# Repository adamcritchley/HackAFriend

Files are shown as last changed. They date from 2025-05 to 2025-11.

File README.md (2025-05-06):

# Hack-A-Friend Handheld Gaming Console

### Hone your hacking skills with the **Hack-A-Friend** gaming handheld!  
Delve into epic **CTF attack and defend** style games with your friends. Challenge opponents by **attacking their devices** while defending your own. The winner unleashes a **devastating payload** to dominate their opponent’s game.

---

## 🔥 Features

- **CTF-style gameplay** – Attack and defend devices in real-time battles.
- **Custom payloads** – Winners can craft unique in-game exploits.
- **Open-source** – Clone our upcoming [GitHub repository](#) and create your own games and payloads.
- **Interactive LEDs** – Visual cues for game status and exploit notifications.
- **Bootloader customization** – Recover or modify firmware when needed.

---

## 🔧 Hardware Specifications

- **Power System**:
  - Lithium-ion battery management chip.
  - 500mA LDO for regulated power.
  - Test points for monitoring:
    - `VCC` (battery power source).
    - `3V3` (regulated output from LDO).

- **LED Indicators**:
  - **System notifications**:
    - `PWR` (Power Health LED).
    - `CHG` (Battery Charging LED).
  - **Game Status**:
    - **NeoPixel**:
      - Off – Game idle.
      - Green – Game active.
      - Red – Device under exploitation.
    - **User-Controlled LEDs**:
      - Two standard LEDs for custom exploit visualizations.

- **Debugging & Recovery**:
  - **Test points** for SDA & SCL (I2C debugging with digital signal analyzer).
  - **Bootloader Recovery**:
    - Uses **10-pin ARM TagConnect footprint** (`TC2050-IDC-NL` cable).
    - Compatible with **SWD** and **JTAG** devices like `nRF52840 DK`.
    - Recovery via `nrf-utils` and official bootloader image.
    - **Segger J-Link compatibility

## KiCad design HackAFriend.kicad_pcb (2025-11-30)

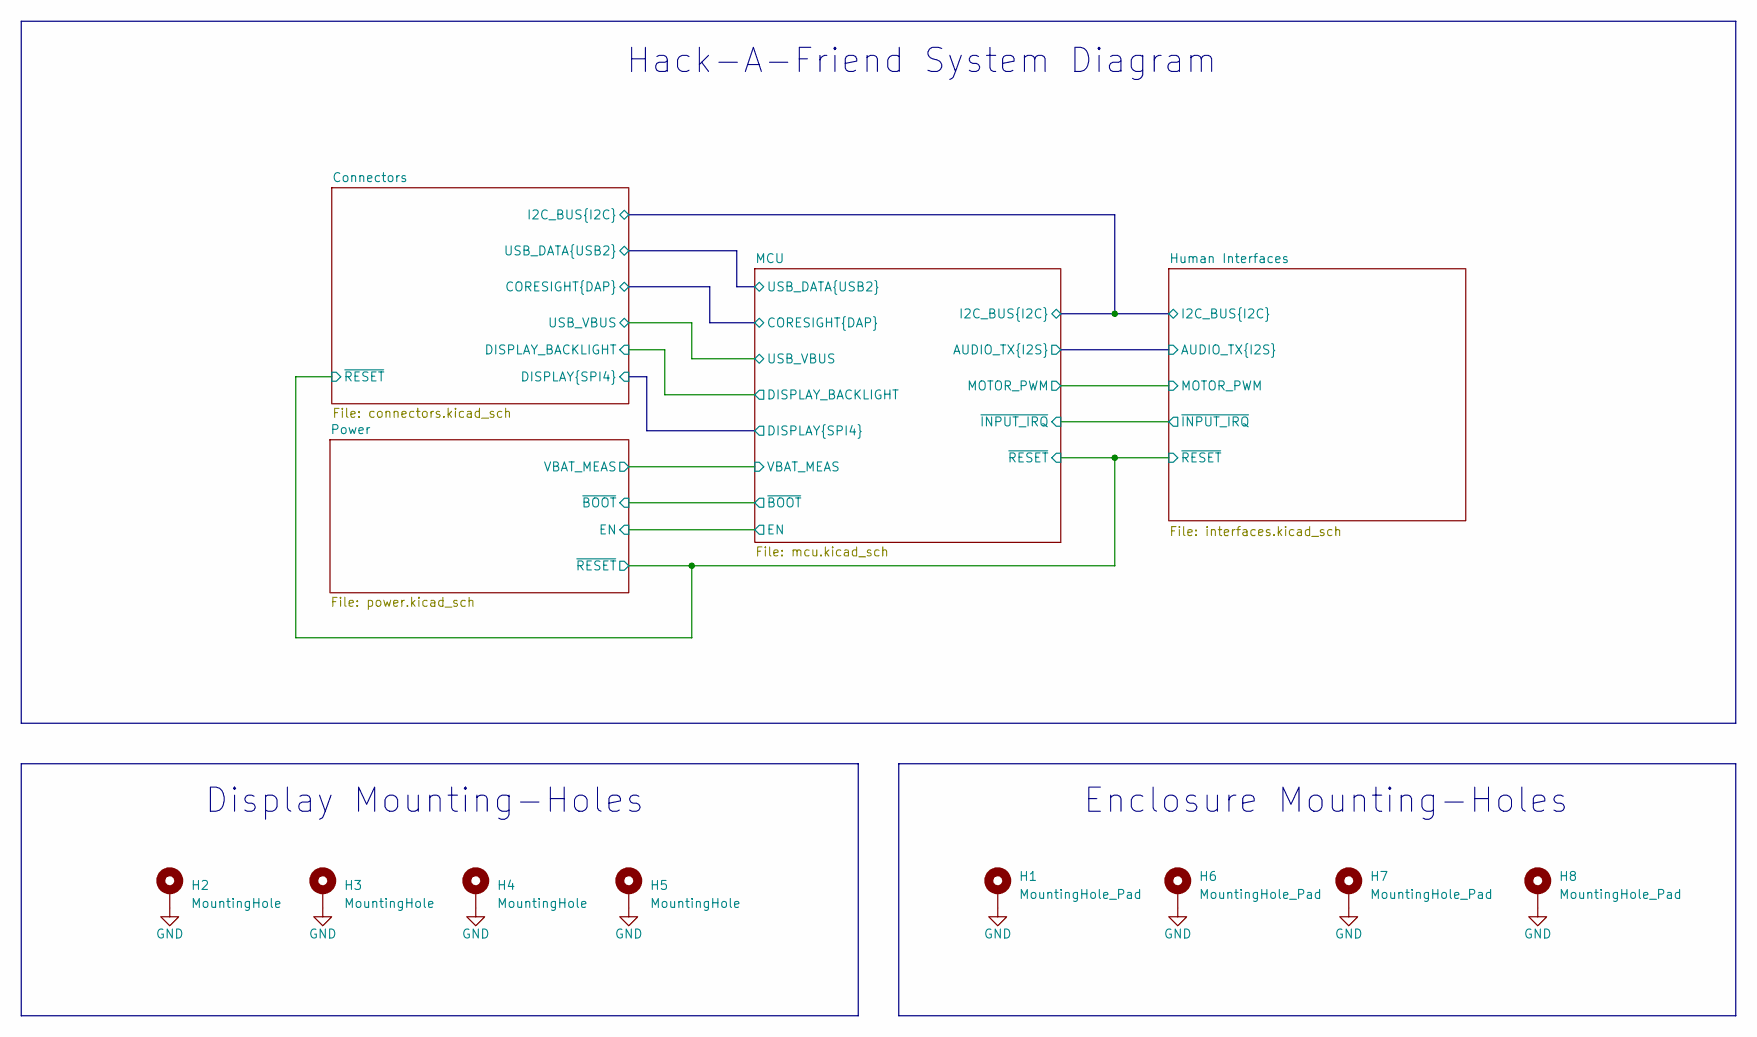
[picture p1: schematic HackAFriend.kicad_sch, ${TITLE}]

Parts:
H1, H6, H7, H8: MountingHole_Pad; MountingHole_2.7mm_M2.5_DIN965_Pad
H2, H3, H4, H5: MountingHole; MountingHole_2.5mm_Pad

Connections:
GND: H1.1, H2.1, H3.1, H4.1, H5.1, H6.1, H7.1, H8.1; also elsewhere on the board

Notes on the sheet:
Display Mounting-Holes
Hack-A-Friend System Diagram
Enclosure Mounting-Holes

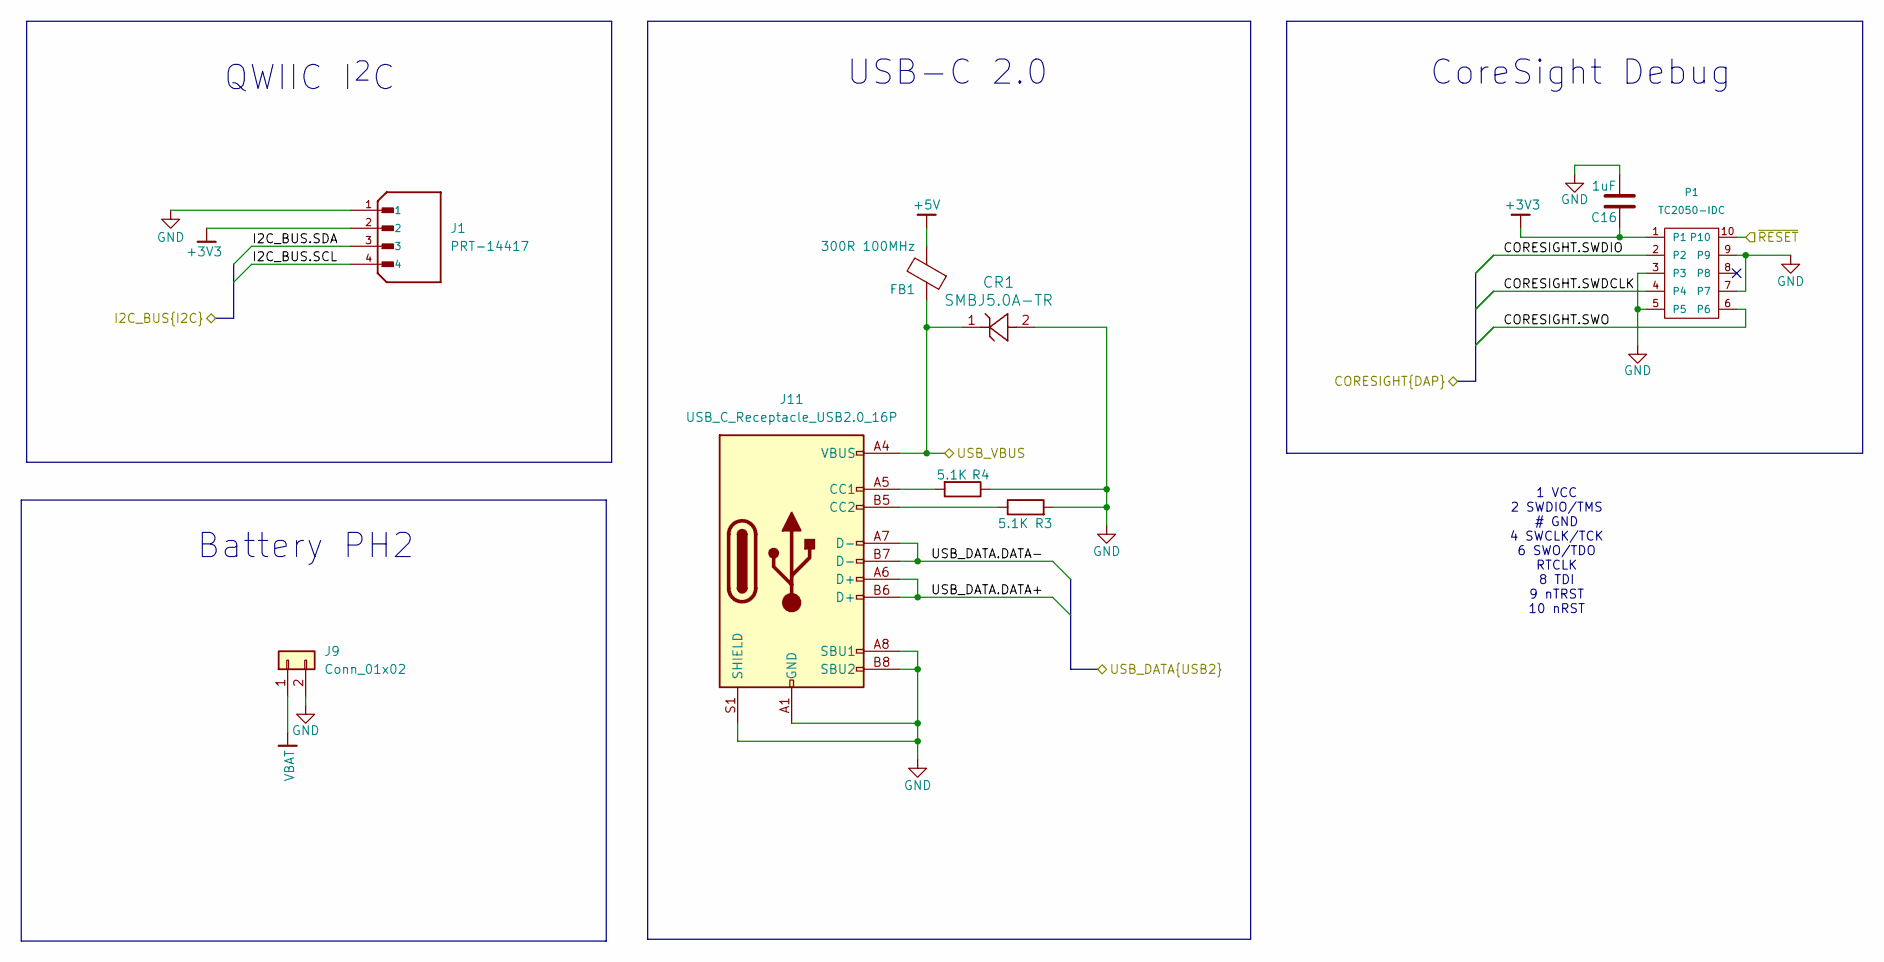
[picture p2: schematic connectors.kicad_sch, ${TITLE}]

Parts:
C16: 1uF; C_0402_1005Metric
CR1: SMBJ5.0A-TR; SMB_STM
FB1: 300R 100MHz; L_0805_2012Metric
J1: PRT-14417; SPARKFUN_PRT-14417; PARTREV NA
J9: Conn_01x02; JST_PH_S2B-PH-K_1x02_P2.00mm_Horizontal
J11: USB_C_Receptacle_USB2.0_16P; USB_C_Receptacle_GCT_USB4105-xx-A_16P_TopMnt_Horizontal
P1: TC2050-IDC; Tag-Connect_TC2050-IDC-FP_2x05_P1.27mm_Vertical
R3, R4: 5.1K; R_0402_1005Metric

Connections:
+3V3: C16.1, J1.2, P1.1; also elsewhere on the board
+5V: FB1.2; also elsewhere on the board
/Connectors/CORESIGHT.SWDCLK: P1.4; also elsewhere on the board
/Connectors/CORESIGHT.SWDIO: P1.2; also elsewhere on the board
/Connectors/CORESIGHT.SWO: P1.6; also elsewhere on the board
/Connectors/I2C_BUS.SCL: J1.4; also elsewhere on the board
/Connectors/I2C_BUS.SDA: J1.3; also elsewhere on the board
/Connectors/USB_DATA.DATA+: J11.A6 (D+), J11.B6 (D+); also elsewhere on the board
/Connectors/USB_DATA.DATA-: J11.A7 (D-), J11.B7 (D-); also elsewhere on the board
/Connectors/USB_VBUS: CR1.1, FB1.1, J11.A4 (VBUS), J11.A9 (VBUS), J11.B4 (VBUS), J11.B9 (VBUS); also elsewhere on the board
/Connectors/~RESET: P1.10; also elsewhere on the board
GND: C16.2, CR1.2, J1.1, J9.2, J11.A1 (GND), J11.A8 (SBU1), J11.A12 (GND), J11.B1 (GND), J11.B8 (SBU2), J11.B12 (GND), J11.S1 (SHIELD), P1.3, P1.5, P1.7, P1.9, R3.2, R4.1; also elsewhere on the board
unnamed: J11.A5 (CC1), R4.2
unnamed: J11.B5 (CC2), R3.1
VBAT: J9.1; also elsewhere on the board

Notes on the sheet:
USB-C 2.0
Battery PH2
QWIIC I^{2}C
1 VCC 2 SWDIO/TMS # GND 4 SWCLK/TCK 6 SWO/TDO RTCLK 8 TDI 9 nTRST 10 nRST
CoreSight Debug

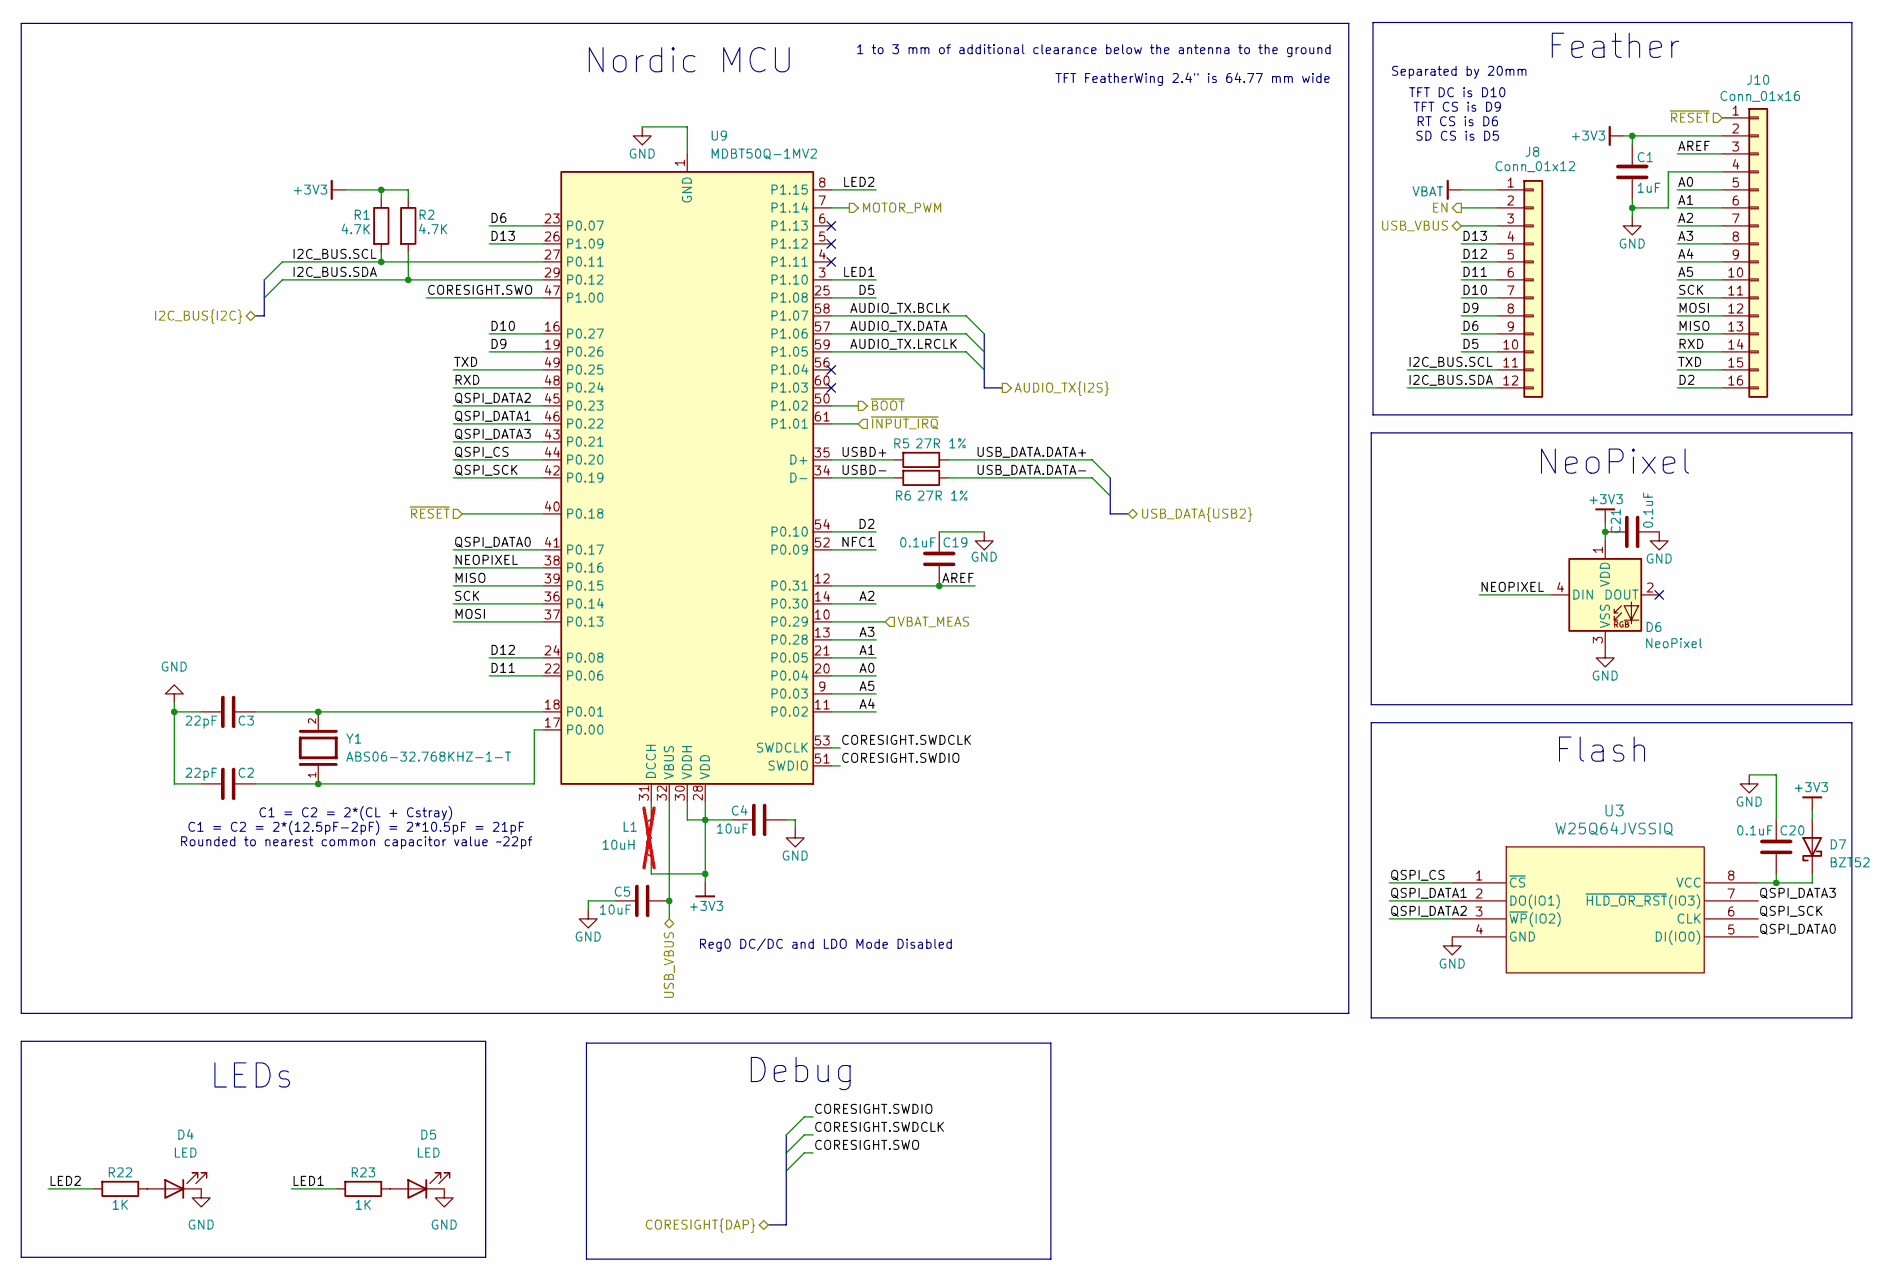
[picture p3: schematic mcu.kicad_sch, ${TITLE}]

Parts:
C1: 1uF; C_0402_1005Metric
C2, C3: 22pF; C_0603_1608Metric
C4, C5: 10uF; C_0603_1608Metric
C19, C20, C21: 0.1uF; C_0402_1005Metric
D4, D5: LED; LED_0603_1608Metric
D6: NeoPixel; LED_WS2812B_PLCC4_5.0x5.0mm_P3.2mm
D7: BZT52; D_0402_1005Metric
J8: Conn_01x12; PinHeader_1x12_P2.54mm_Vertical_SMD_Pin1Left
J10: Conn_01x16; PinHeader_1x16_P2.54mm_Vertical_SMD_Pin1Left
L1: 10uH; L_0603_1608Metric; not fitted
R1, R2: 4.7K; R_0603_1608Metric
R5, R6: 27R 1%; R_0402_1005Metric
R22, R23: 1K; R_0603_1608Metric
U3: W25Q64JVSSIQ; SOIC-8_5P28X5P28_WIN
U9: MDBT50Q-1MV2; Raytac_MDBT50Q
Y1: ABS06-32.768KHZ-1-T; XTAL_ABS06-32.768KHZ-1-T; PARTREV 4/25/2022

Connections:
+3V3: C1.1, C4.2, C21.2, D6.1 (VDD), D7.2 (A), J10.2, L1.1, R1.1, R2.1, U9.28 (VDD), U9.30 (VDDH); also elsewhere on the board
/Connectors/CORESIGHT.SWDCLK: U9.53 (SWDCLK); also elsewhere on the board
/Connectors/CORESIGHT.SWDIO: U9.51 (SWDIO); also elsewhere on the board
/Connectors/CORESIGHT.SWO: U9.47 (P1.00); also elsewhere on the board
/Connectors/I2C_BUS.SCL: J8.11, R1.2, U9.27 (P0.11); also elsewhere on the board
/Connectors/I2C_BUS.SDA: J8.12, R2.2, U9.29 (P0.12); also elsewhere on the board
/Connectors/USB_DATA.DATA+: R5.1; also elsewhere on the board
/Connectors/USB_DATA.DATA-: R6.1; also elsewhere on the board
/Connectors/USB_VBUS: C5.1, J8.3, U9.32 (VBUS); also elsewhere on the board
/Connectors/~RESET: J10.1, U9.40 (P0.18); also elsewhere on the board
/Human Interfaces/AUDIO_TX.BCLK: U9.58 (P1.07); also elsewhere on the board
/Human Interfaces/AUDIO_TX.DATA: U9.57 (P1.06); also elsewhere on the board
/Human Interfaces/AUDIO_TX.LRCLK: U9.59 (P1.05); also elsewhere on the board
/Human Interfaces/MOTOR_PWM: U9.7 (P1.14); also elsewhere on the board
/Human Interfaces/~INPUT_IRQ: U9.61 (P1.01); also elsewhere on the board
/MCU/A0: J10.5, U9.20 (P0.04)
/MCU/A1: J10.6, U9.21 (P0.05)
/MCU/A2: J10.7, U9.14 (P0.30)
/MCU/A3: J10.8, U9.13 (P0.28)
/MCU/A4: J10.9, U9.11 (P0.02)
/MCU/A5: J10.10, U9.9 (P0.03)
/MCU/AREF: C19.1, J10.3, U9.12 (P0.31)
/MCU/D2: J10.16, U9.54 (P0.10)
/MCU/D5: J8.10, U9.25 (P1.08)
/MCU/D6: J8.9, U9.23 (P0.07)
/MCU/D9: J8.8, U9.19 (P0.26)
/MCU/D10: J8.7, U9.16 (P0.27)
/MCU/D11: J8.6, U9.22 (P0.06)
/MCU/D12: J8.5, U9.24 (P0.08)
/MCU/D13: J8.4, U9.26 (P1.09)
/MCU/EN: J8.2; also elsewhere on the board
/MCU/LED1: R23.2, U9.3 (P1.10)
/MCU/LED2: R22.2, U9.8 (P1.15)
/MCU/MISO: J10.13, U9.39 (P0.15)
/MCU/MOSI: J10.12, U9.37 (P0.13)
/MCU/NEOPIXEL: D6.4 (DIN), U9.38 (P0.16)
/MCU/NFC1: U9.52 (P0.09)
/MCU/QSPI_CS: U3.1 (~CS), U9.44 (P0.20)
/MCU/QSPI_DATA0: U3.5 (DI(IO0)), U9.41 (P0.17)
/MCU/QSPI_DATA1: U3.2 (DO(IO1)), U9.46 (P0.22)
/MCU/QSPI_DATA2: U3.3 (~WP(IO2)), U9.45 (P0.23)
/MCU/QSPI_DATA3: U3.7 (~HLD_OR_RST(IO3)), U9.43 (P0.21)
/MCU/QSPI_SCK: U3.6 (CLK), U9.42 (P0.19)
/MCU/RXD: J10.14, U9.48 (P0.24)
/MCU/SCK: J10.11, U9.36 (P0.14)
/MCU/TXD: J10.15, U9.49 (P0.25)
/MCU/USBD+: R5.2, U9.35 (D+)
/MCU/USBD-: R6.2, U9.34 (D-)
/MCU/VBAT_MEAS: U9.10 (P0.29); also elsewhere on the board
/MCU/~BOOT: U9.50 (P1.02); also elsewhere on the board
GND: C1.2, C2.1, C3.1, C4.1, C5.2, C19.2, C20.2, C21.1, D4.1 (K), D5.1 (K), D6.3 (VSS), J10.4, U3.4 (GND), U9.1 (GND), U9.2 (GND), U9.15 (GND), U9.33 (GND), U9.55 (GND); also elsewhere on the board
unnamed: D4.2 (A), R22.1
unnamed: D5.2 (A), R23.1
unnamed: C20.1, D7.1 (K), U3.8 (VCC)
unnamed: L1.2, U9.31 (DCCH)
unnamed: C2.2, U9.17 (P0.00), Y1.1
unnamed: C3.2, U9.18 (P0.01), Y1.2
VBAT: J8.1; also elsewhere on the board

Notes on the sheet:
TFT DC is D10 TFT CS is D9 RT CS is D6 SD CS is D5
Debug
C1 = C2 = 2*(CL + Cstray) C1 = C2 = 2*(12.5pF-2pF) = 2*10.5pF = 21pF Rounded to nearest common capacitor value ~22pf
LEDs
Feather
Reg0 DC/DC and LDO Mode Disabled
NeoPixel
TFT FeatherWing 2.4" is 64.77 mm wide
Separated by 20mm
Flash
1 to 3 mm of additional clearance below the antenna to the ground
Nordic MCU

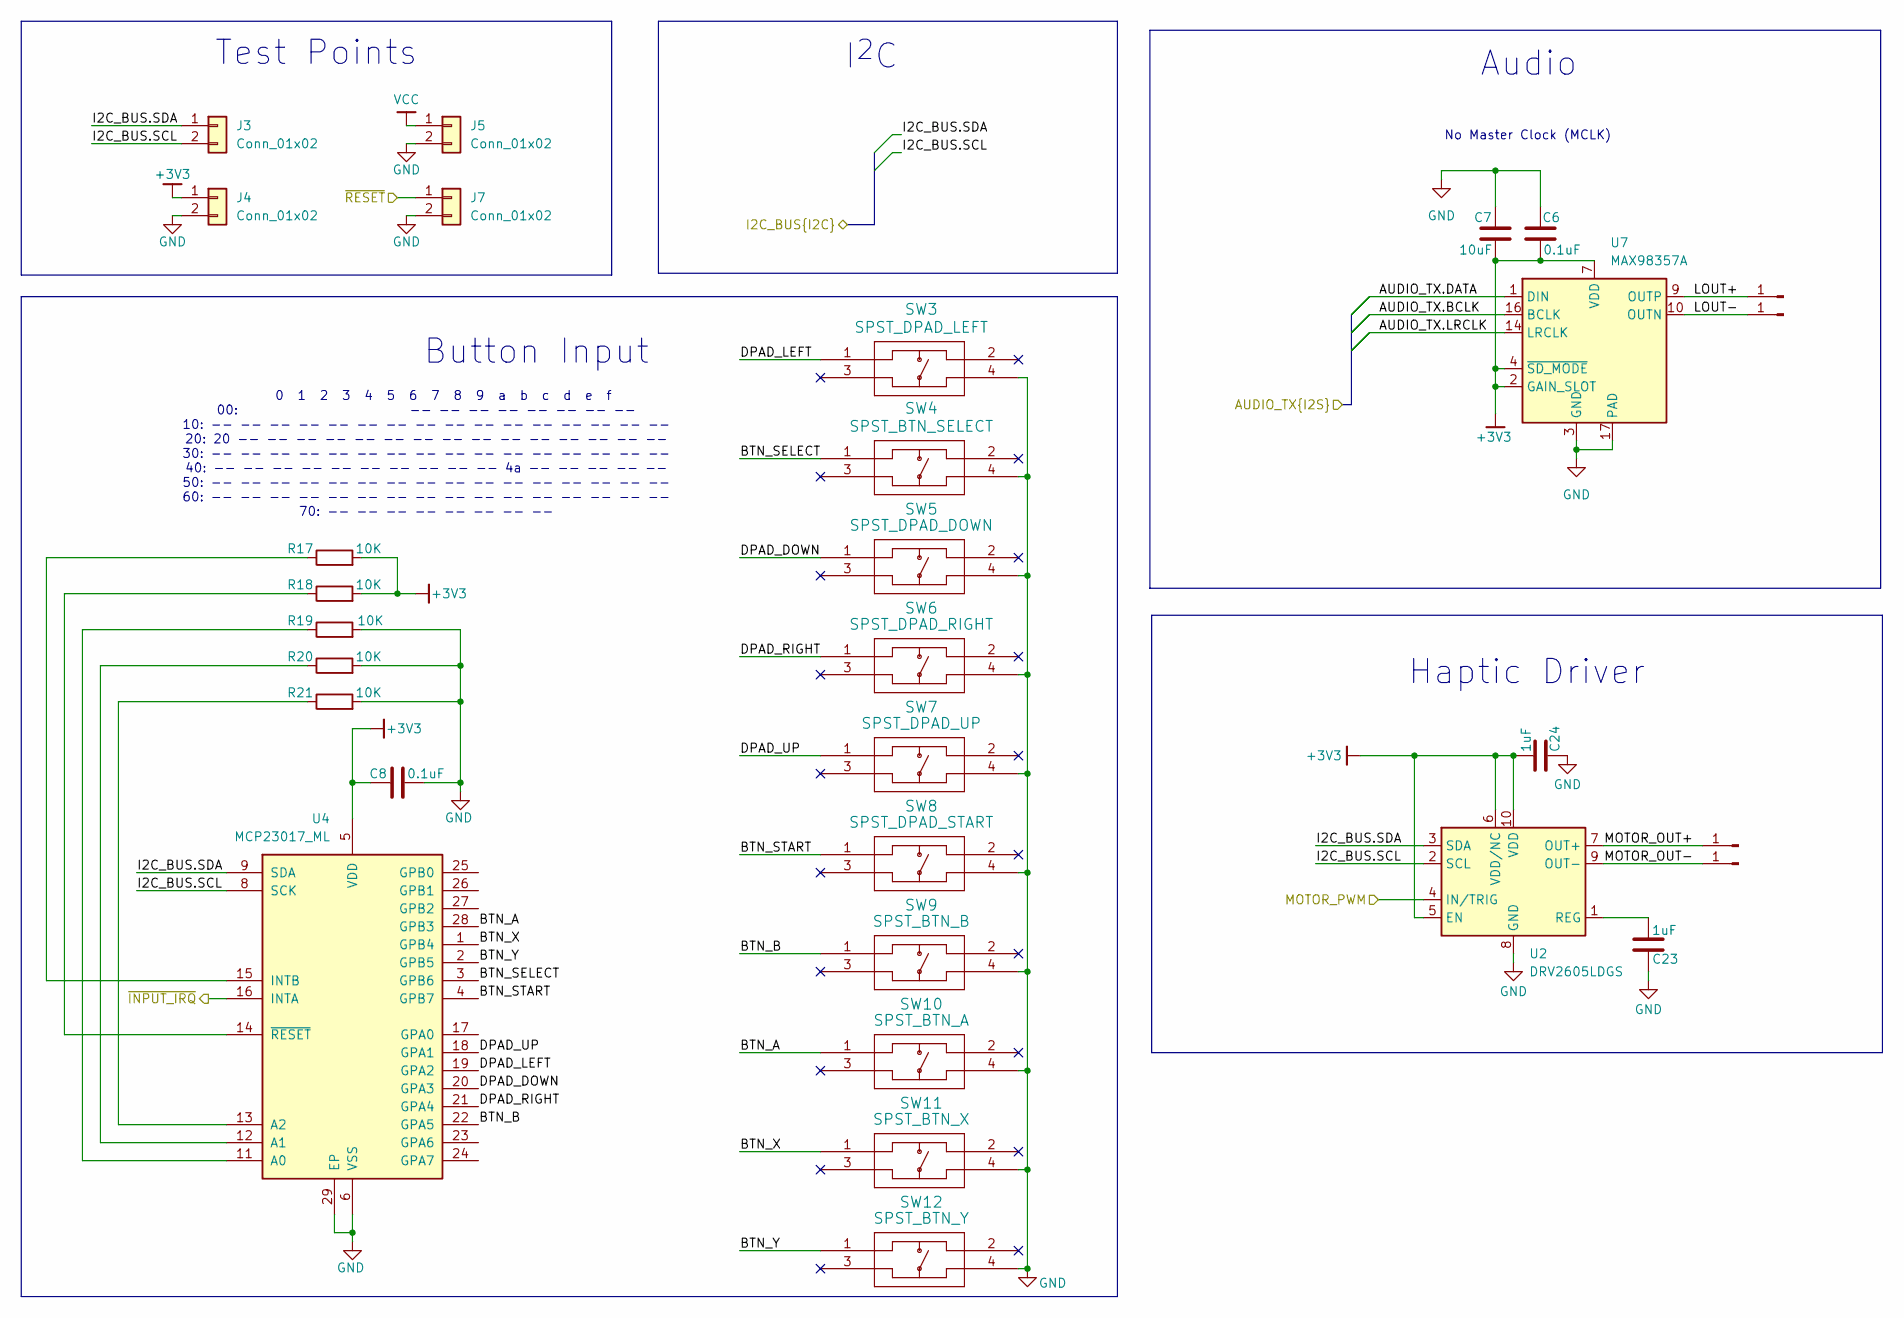
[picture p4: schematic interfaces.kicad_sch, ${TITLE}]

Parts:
C6, C8: 0.1uF; C_0402_1005Metric
C7: 10uF; C_0603_1608Metric
C23, C24: 1uF; C_0603_1608Metric
J3, J4, J5, J7: Conn_01x02; PinHeader_1x02_P2.54mm_Vertical
LPAD_OUT+1, LPAD_OUT+2: Conn_01x01_Pin; SolderWirePad_1x01_SMD_1x2mm
LPAD_OUT-1, LPAD_OUT-2: Conn_01x01_Pin; SolderWirePad_1x01_SMD_1x2mm
R17, R18, R19, R20, R21: 10K; C_0402_1005Metric
SW3: SPST_DPAD_LEFT; SW_PTS_647_SN50_SMTR2_LFS; PARTREV 4 Apr 22; DigiKey_Part_Number PTS647SN50SMTR2LFSTR-ND
SW4: SPST_BTN_SELECT; SW_PTS_647_SN50_SMTR2_LFS; PARTREV 4 Apr 22; DigiKey_Part_Number PTS647SN50SMTR2LFSTR-ND
SW5: SPST_DPAD_DOWN; SW_PTS_647_SN50_SMTR2_LFS; PARTREV 4 Apr 22; DigiKey_Part_Number PTS647SN50SMTR2LFSTR-ND
SW6: SPST_DPAD_RIGHT; SW_PTS_647_SN50_SMTR2_LFS; PARTREV 4 Apr 22; DigiKey_Part_Number PTS647SN50SMTR2LFSTR-ND
SW7: SPST_DPAD_UP; SW_PTS_647_SN50_SMTR2_LFS; PARTREV 4 Apr 22; DigiKey_Part_Number PTS647SN50SMTR2LFSTR-ND
SW8: SPST_DPAD_START; SW_PTS_647_SN50_SMTR2_LFS; PARTREV 4 Apr 22; DigiKey_Part_Number PTS647SN50SMTR2LFSTR-ND
SW9: SPST_BTN_B; SW_PTS_647_SN50_SMTR2_LFS; PARTREV 4 Apr 22; DigiKey_Part_Number PTS647SN50SMTR2LFSTR-ND
SW10: SPST_BTN_A; SW_PTS_647_SN50_SMTR2_LFS; PARTREV 4 Apr 22; DigiKey_Part_Number PTS647SN50SMTR2LFSTR-ND
SW11: SPST_BTN_X; SW_PTS_647_SN50_SMTR2_LFS; PARTREV 4 Apr 22; DigiKey_Part_Number PTS647SN50SMTR2LFSTR-ND
SW12: SPST_BTN_Y; SW_PTS_647_SN50_SMTR2_LFS; PARTREV 4 Apr 22; DigiKey_Part_Number PTS647SN50SMTR2LFSTR-ND
U2: DRV2605LDGS; VSSOP-10_3x3mm_P0.5mm
U4: MCP23017_ML; QFN-28-1EP_6x6mm_P0.65mm_EP4.25x4.25mm
U7: MAX98357A; TQFN-16-1EP_3x3mm_P0.5mm_EP1.23x1.23mm

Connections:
+3V3: C6.1, C7.1, C8.2, C24.2, J4.1, R17.2, R18.2, U2.5 (EN), U2.6 (VDD/NC), U2.10 (VDD), U4.5 (VDD), U7.2 (GAIN_SLOT), U7.4 (~SD_MODE), U7.7 (VDD), U7.8 (VDD); also elsewhere on the board
/Connectors/I2C_BUS.SCL: J3.2, U2.2 (SCL), U4.8 (SCK); also elsewhere on the board
/Connectors/I2C_BUS.SDA: J3.1, U2.3 (SDA), U4.9 (SDA); also elsewhere on the board
/Connectors/~RESET: J7.1; also elsewhere on the board
/Human Interfaces/AUDIO_TX.BCLK: U7.16 (BCLK); also elsewhere on the board
/Human Interfaces/AUDIO_TX.DATA: U7.1 (DIN); also elsewhere on the board
/Human Interfaces/AUDIO_TX.LRCLK: U7.14 (LRCLK); also elsewhere on the board
/Human Interfaces/BTN_A: SW10.1, U4.28 (GPB3)
/Human Interfaces/BTN_B: SW9.1, U4.22 (GPA5)
/Human Interfaces/BTN_SELECT: SW4.1, U4.3 (GPB6)
/Human Interfaces/BTN_START: SW8.1, U4.4 (GPB7)
/Human Interfaces/BTN_X: SW11.1, U4.1 (GPB4)
/Human Interfaces/BTN_Y: SW12.1, U4.2 (GPB5)
/Human Interfaces/DPAD_DOWN: SW5.1, U4.20 (GPA3)
/Human Interfaces/DPAD_LEFT: SW3.1, U4.19 (GPA2)
/Human Interfaces/DPAD_RIGHT: SW6.1, U4.21 (GPA4)
/Human Interfaces/DPAD_UP: SW7.1, U4.18 (GPA1)
/Human Interfaces/LOUT+: LPAD_OUT+2.1, U7.9 (OUTP)
/Human Interfaces/LOUT-: LPAD_OUT-2.1, U7.10 (OUTN)
/Human Interfaces/MOTOR_OUT+: LPAD_OUT+1.1, U2.7 (OUT+)
/Human Interfaces/MOTOR_OUT-: LPAD_OUT-1.1, U2.9 (OUT-)
/Human Interfaces/MOTOR_PWM: U2.4 (IN/TRIG); also elsewhere on the board
/Human Interfaces/~INPUT_IRQ: U4.16 (INTA); also elsewhere on the board
GND: C6.2, C7.2, C8.1, C23.1, C24.1, J4.2, J5.2, J7.2, R19.2, R20.2, R21.2, SW3.4, SW4.4, SW5.4, SW6.4, SW7.4, SW8.4, SW9.4, SW10.4, SW11.4, SW12.4, U2.8 (GND), U4.6 (VSS), U4.29 (EP), U7.3 (GND), U7.11 (GND), U7.15 (GND), U7.17 (PAD); also elsewhere on the board
unnamed: C23.2, U2.1 (REG)
unnamed: R19.1, U4.11 (A0)
unnamed: R20.1, U4.12 (A1)
unnamed: R21.1, U4.13 (A2)
unnamed: R17.1, U4.15 (INTB)
unnamed: R18.1, U4.14 (~RESET)
VCC: J5.1; also elsewhere on the board

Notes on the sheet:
Test Points
Audio
I^{2}C
No Master Clock (MCLK)
Button Input
0 1 2 3 4 5 6 7 8 9 a b c d e f 00: -- -- -- -- -- -- -- -- 10: -- -- -- -- -- -- -- -- -- -- -- -- -- -- -- -- 20: 20 -- -- -- -- -- -- -- -- -- -- -- -- -- -- -- 30: -- -- -- -- -- -- -- -- -- -- -- -- -- -- -- -- 40: -- -- -- -- -- -- -- -- -- -- 4a -- -- -- -- -- 50: -- -- -- -- -- -- -- -- -- 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
Haptic Driver

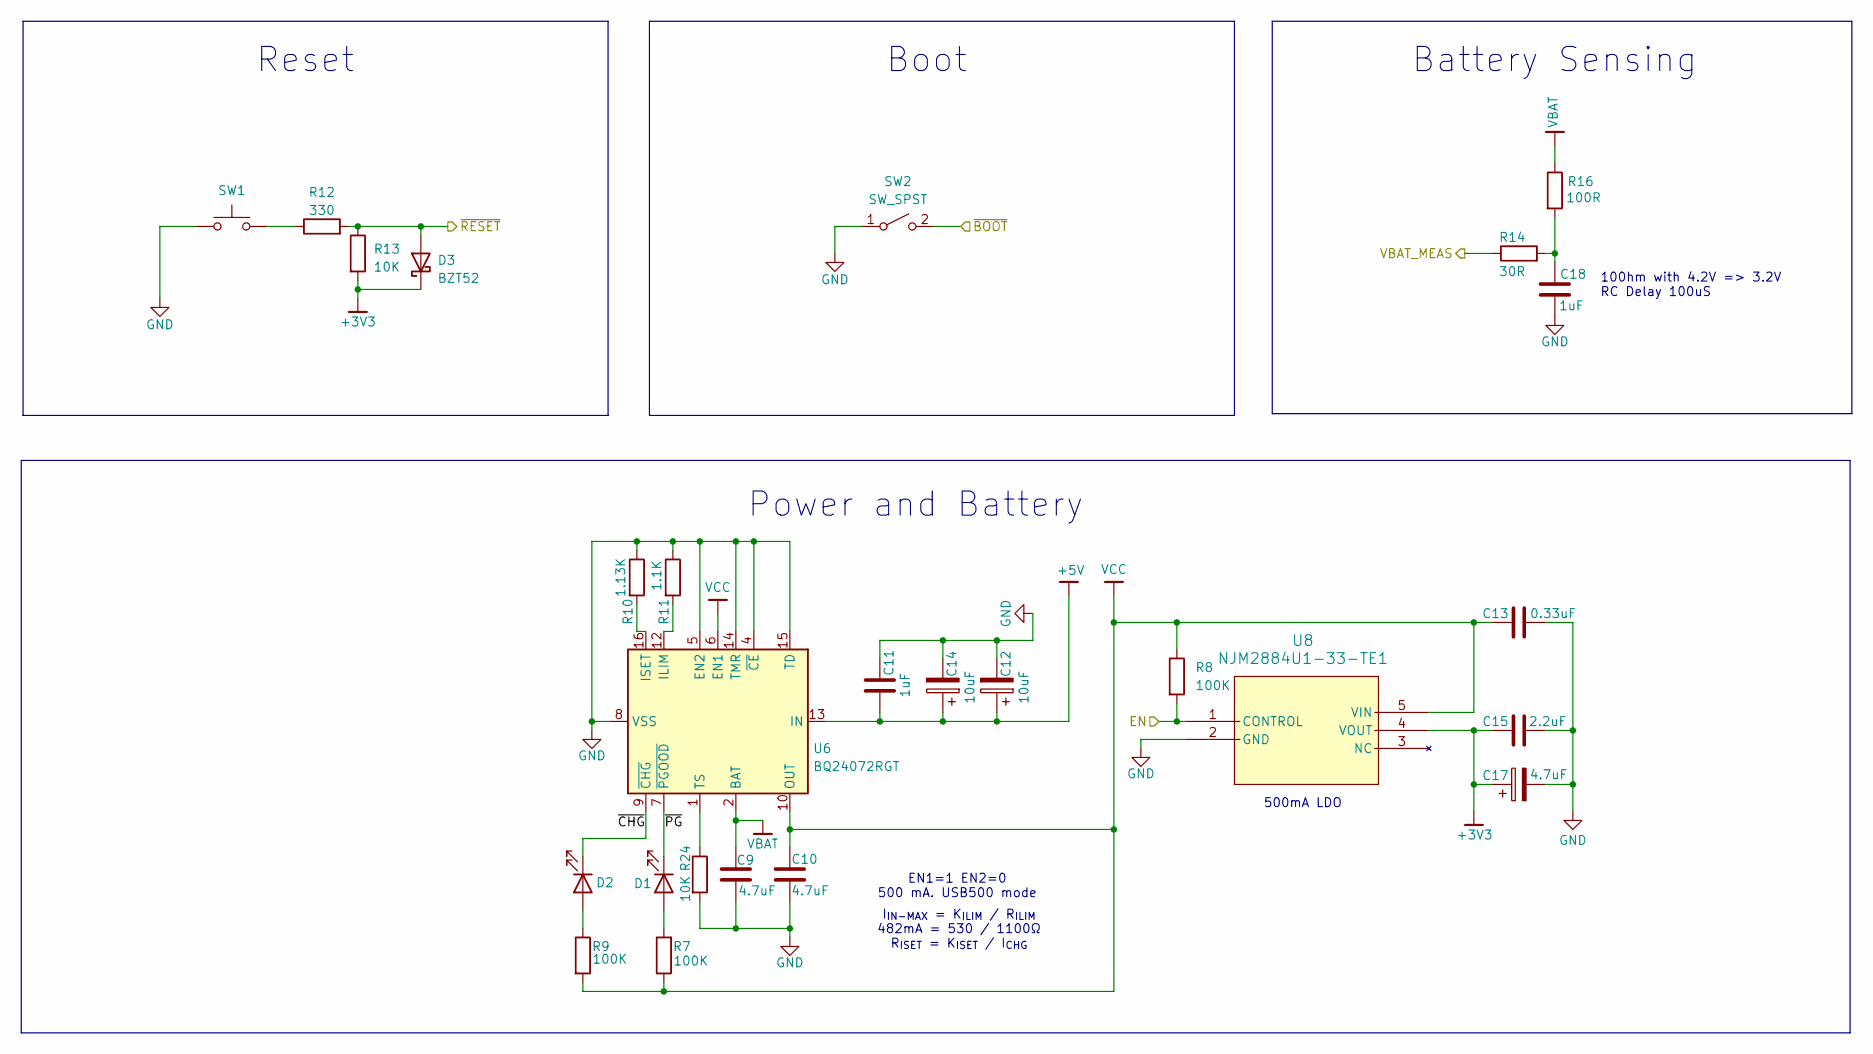
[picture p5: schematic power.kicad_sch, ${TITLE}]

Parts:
C9, C10: 4.7uF; C_0603_1608Metric
C11: 1uF; C_0603_1608Metric
C12, C14: 10uF; CP_EIA-3528-15_AVX-H
C13: 0.33uF; C_0603_1608Metric
C15: 2.2uF; C_0603_1608Metric
C17: 4.7uF; CP_EIA-1608-08_AVX-J
C18: 1uF; C_0402_1005Metric
D1, D2: LTST-S270TBKT; LED_0603_1608Metric
D3: BZT52; D_0402_1005Metric
R7, R8, R9: 100K; R_0603_1608Metric
R10: 1.13K; R_0402_1005Metric
R11: 1.1K; R_0402_1005Metric
R12: 330; R_0603_1608Metric
R13, R24: 10K; R_0402_1005Metric
R14: 30R; R_0402_1005Metric
R16: 100R; R_0402_1005Metric
SW1: SW_SPST_Omron_B3F-315x_Angled
SW2: SW_SPST; SW_SPST_B3U-1000P
U6: BQ24072RGT; VQFN-16-1EP_3x3mm_P0.5mm_EP1.6x1.6mm
U8: NJM2884U1-33-TE1; SOT89-5-1&slash_2_NWJ

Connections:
+3V3: C15.1, C17.1, D3.1 (K), R13.2, U8.4 (VOUT); also elsewhere on the board
+5V: C11.2, C12.1, C14.1, U6.13 (IN); also elsewhere on the board
/Connectors/~RESET: D3.2 (A), R12.2, R13.1; also elsewhere on the board
/MCU/EN: R8.2, U8.1 (CONTROL); also elsewhere on the board
/MCU/VBAT_MEAS: R14.1; also elsewhere on the board
/MCU/~BOOT: SW2.2 (B); also elsewhere on the board
/Power/~CHG: D2.1 (K), U6.9 (~CHG)
/Power/~PG: D1.1 (K), U6.7 (~PGOOD)
GND: C9.2, C10.2, C11.1, C12.2, C13.2, C14.2, C15.2, C17.2, C18.2, R10.1, R11.1, R24.2, SW1.1, SW2.1 (A), U6.4 (~CE), U6.5 (EN2), U6.8 (VSS), U6.14 (TMR), U6.15 (TD), U6.17 (VSS), U8.2 (GND); also elsewhere on the board
unnamed: C18.1, R14.2, R16.2
unnamed: D1.2 (A), R7.2
unnamed: D2.2 (A), R9.1
unnamed: R12.1, SW1.2
unnamed: R11.2, U6.12 (ILIM)
unnamed: R10.2, U6.16 (ISET)
unnamed: R24.1, U6.1 (TS)
VBAT: C9.1, R16.1, U6.2 (BAT), U6.3 (BAT); also elsewhere on the board
VCC: C10.1, C13.1, R7.1, R8.1, R9.2, U6.6 (EN1), U6.10 (OUT), U6.11 (OUT), U8.5 (VIN); also elsewhere on the board

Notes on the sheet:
Power and Battery
500mA LDO
I_{IN-MAX} = K_{ILIM} / R_{ILIM} 482mA = 530 / 1100Ω R_{ISET} = K_{ISET} / I_{CHG}
100hm with 4.2V => 3.2V RC Delay 100uS
Reset
Boot
EN1=1 EN2=0 500 mA. USB500 mode
Battery Sensing

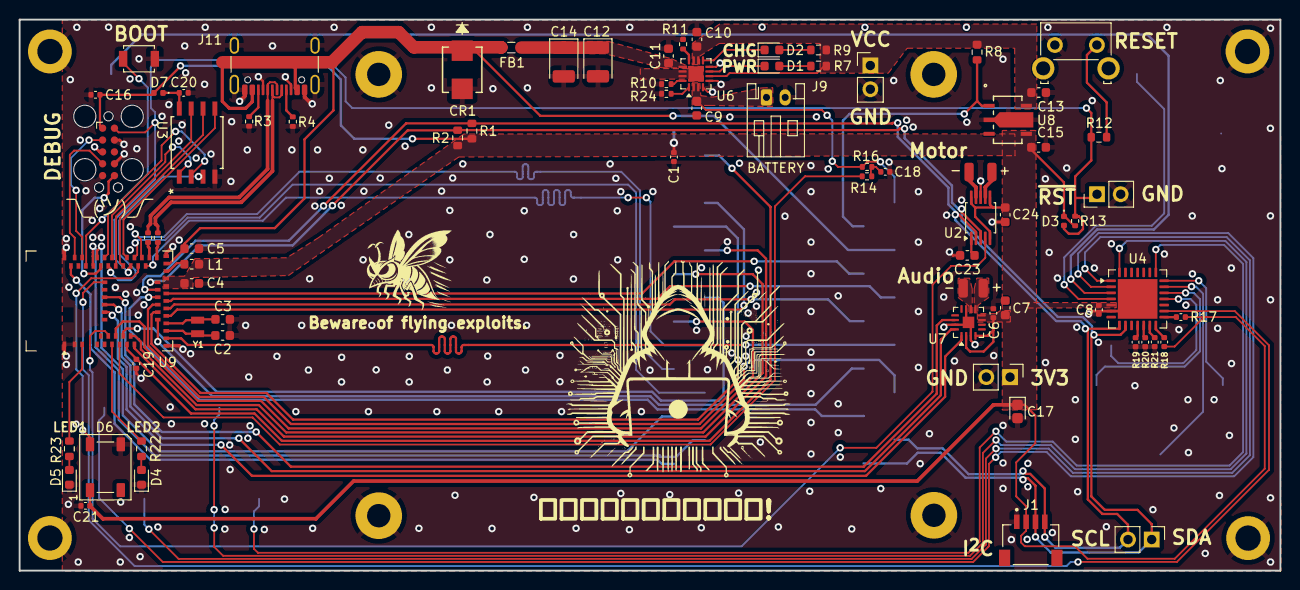
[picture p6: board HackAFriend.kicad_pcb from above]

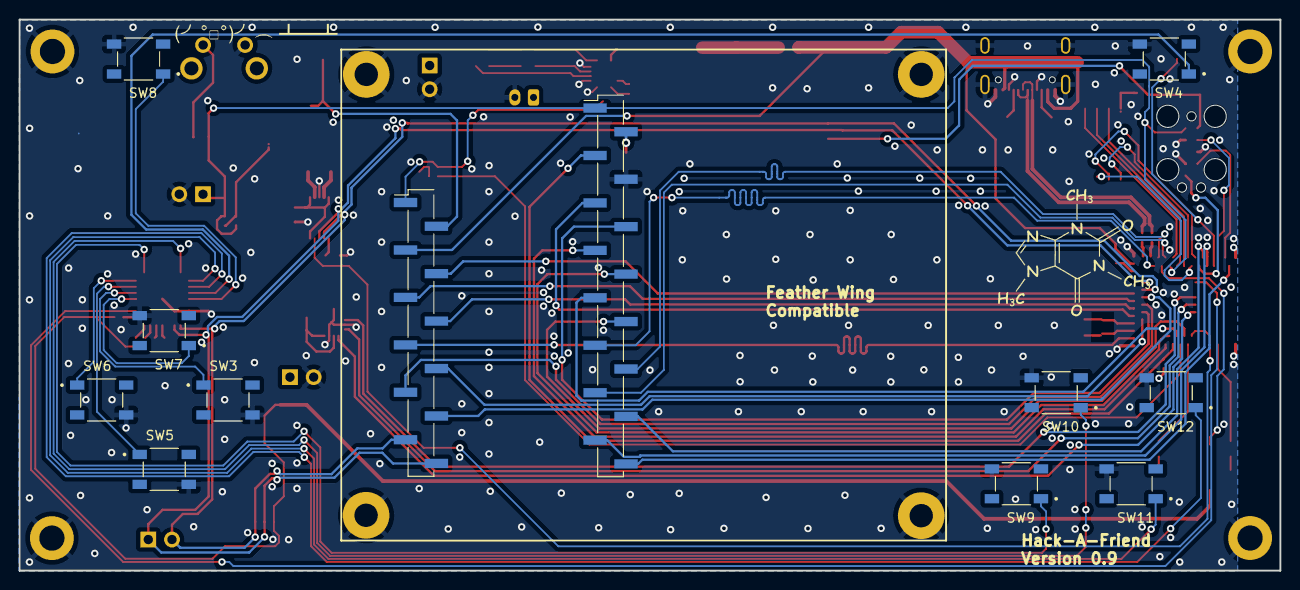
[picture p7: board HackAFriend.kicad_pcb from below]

Board: 2 copper layers, 135.0 x 59.0 mm, 98 parts (12 on the bottom side), 90 nets.

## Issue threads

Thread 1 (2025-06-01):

clean up design

adamcritchley, 2025-06-01:
Change TagConnect to footprint with legs, move NRF52 to edge of board, and clean up traces by reducing vias and simplifying routing.

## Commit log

2025-05-06 Initial release
    HackAFriend v1A release
    [HackAFriend.kicad_pcb, HackAFriend.kicad_sch, connectors.kicad_sch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]
2025-05-06 Create Hackafriend_BOM_PCBWay.xlsx
    Add PCBWay BOM
    [Hackafriend_BOM_PCBWay.xlsx]
2025-06-01 Release candidate
    Changed USBC connector, changed TagConnect to use footprint with legs, move NRF52 to edge of board, clean up traces
    [HackAFriend.kicad_pcb, connectors.kicad_sch, interfaces.kicad_sch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]
2025-06-03 Change button footprint
    Change button footprint to PTS647 and add a few more stitching vias.
    [HackAFriend.kicad_pcb, interfaces.kicad_sch]
2025-06-06 Update part numbers
    Update part numbers for 12 and 16 PIN SMD 2.54mm pins and USB-C 2.0 connector.
    [HackAFriend.kicad_pcb, connectors.kicad_sch, mcu.kicad_sch]
2025-06-21 Add bypass capacitor
    Added bypass capacitor on VBUS for MCU
    [HackAFriend.kicad_pcb, mcu.kicad_sch]
2025-08-06 Tweak locations and add a bypass capacitor for VBUS
    [HackAFriend.kicad_pcb, connectors.kicad_sch]
2025-08-06 Clean up locations
    [mcu.kicad_sch]
2025-08-10 Replaced DA7280 with DRV2605
    Replaced DA7280 with DRV2605 to simplify board support code in Hack-A-Friend Arduino Library.
    [HackAFriend.kicad_pcb, HackAFriend.kicad_sch, interfaces.kicad_sch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]
2025-11-09 Changed reset button, upgrade to new KiCad
    [HackAFriend.kicad_pcb, Hackafriend_BOM_PCBWay.xlsx, mcu.kicad_sch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]
2025-11-30 Added MP part number fields to schematic and PCB design,
    [HackAFriend.kicad_pcb, interfaces.kicad_sch, mcu.kicad_sch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]

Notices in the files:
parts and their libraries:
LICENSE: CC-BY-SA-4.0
